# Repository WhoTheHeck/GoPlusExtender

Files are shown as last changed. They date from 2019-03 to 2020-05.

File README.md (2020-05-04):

# GoPlusExtender



Demo video (https://youtu.be/t_YZIJWOh5c)

## Idea
The goal of this project is to have the Go Plus modded in a way where it behaves comparable to the simple mod where you solder the vibration motor to the switch. In that simple mod basically everytime you plus would vibrate it will push the button automatically. At the end this results in constant button presses which on one hand drains the battery and on the other hand also always will push the button in events like "catch/spin succesfull", "item bag full", "connection-errors", etc.  
This project aims to react to Go Plus events in a smart way. Only pushing the button when it is necassary. While implementing that there were other convinient features addied like a rechargable LiPo-battery, low battery indicator, manual/automatic mode select, power save functionalities, change to manual catch mode for new pokemon and -very handy- custom vibration motor control! That enables custom vibration patterns which vibrate the motor in automation mode only when e.q. Go Plus disconnects from smartphone, item bag full or pokemon storage full.

## Concept
Hook into LED driving transistors to analize patterns.  
ATTiny45 reads LED signals, processes them, controlls button and vibration motor. Will be in deep sleep when using manual mode

## Partlist
- Battery - ZIPPY 240mAh 20C Single Cell (hobbyking)
- TP4056 Lithium Battery Charger and Protection Module
- PCB components (see BOM in files)
- additional 5.1k 0603 for charge controller PCB --> exchange R3, limits charge current to save limit around 250mA
- 1x 3D printed case top
- 1x 3D printed case bottom
- 1x 3D printed programmer adapter
- 2x PoGo-Pins small (A=4mm, goes in case, for powering GoPlusExtender from battery), (I got them from Aliexpress, Brand TangDa)
- 7x PoGo-Pins long (A=11.5mm, for programmer), (I got them from Aliexpress, Brand(?) TangDa)

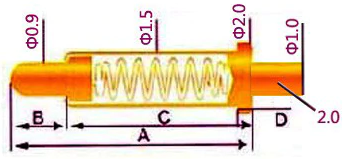
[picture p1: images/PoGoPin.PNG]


## Schematic
find v1 in files  

## Layout
Due to the tiny footprint the PCB had to be done as 4layer board.  
find v1 in files  

## PCB
Necessary components can be found in PCB_BoM.html  
Everything can still be soldered by hand. Using flux is recommended, especially the Analog Switch with the TSSOP-footprint will be trick otherwise.  

## Go Plus Solderpoints & Wiring
Soldering to the LED drivers is the most challenging part, take your time. In that case I recoommend securing the wires with some hot glue (not good practice... I know).  
o Polarity doesn't matter  
W1 --> GoPlusPower+ (from battery connector)  
W2 --> GoPlusPower- (from battery connector)  
W3 --> BatteryPower+ (from BatteryPCB)  
W4 --> BatteryPower- (from BatteryPCB)  
W5 --> switch (from GoPlus upper left)  
W6 --> GoPlus- (where motor was soldered to GoPlus) o  
W7 --> GoPlus+ (where motor was soldered to GoPlus) o  
W8 --> Motor- (desolder from GoPlus, solder here) o  
W9 --> Motor+ (desolder from GoPlus, solder here) o  
W10 --> LED blue (upper IC, upper middle leg)  
W16 --> LED green (lower IC, lower middle leg)  
W18 --> LED red (upper IC, lower middle leg)  
W11,W12,W13,W14,W17 --> Programmer (careful: here correct polarity is important!)  

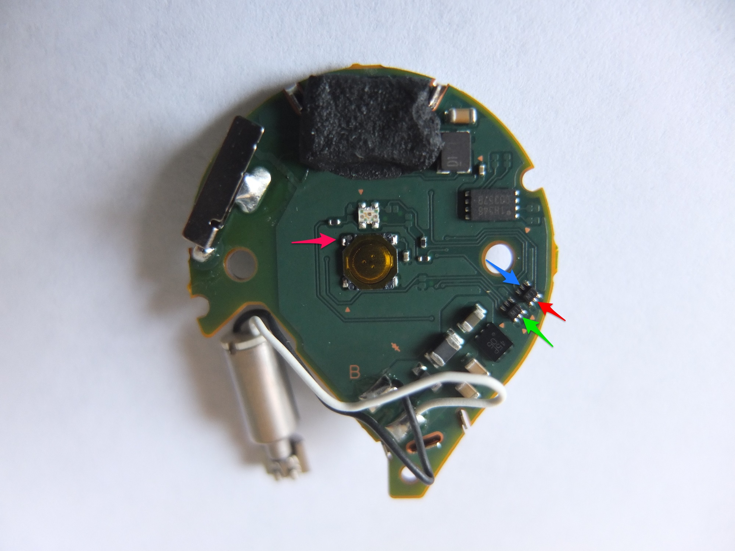
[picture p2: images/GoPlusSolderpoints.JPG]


## Programmer setup
3D printable programmer adapter in files. Needs PoGo-Pins with length = TBD!!!
W11 --> Uno GND
W --> Uno 13 - white
W --> Uno 12 - brown
W --> Uno 11 - purple
W --> Uno 10 - grey
W12 --> Uno 5V

Set mode to manuel when reprogramming!  
Search online for instructions to use Arduino Uno as programmer for ATTinys.

## Assembly

- 3D print case
- add PoGo-Pins to Case, position might needs to be adjusted a little by heating while soldering (needs case-rework)
- solder wires to ChargePCB
- wrap battery in isolation/kapton tape
(change ChargePCB current resistor to xxx ohms)
- attach battery to charge-PCB as seen in pictures
- put battery unit in bottom part, PCB will snapfit in place
- liftup battery, solder wires to PoGo-Pins
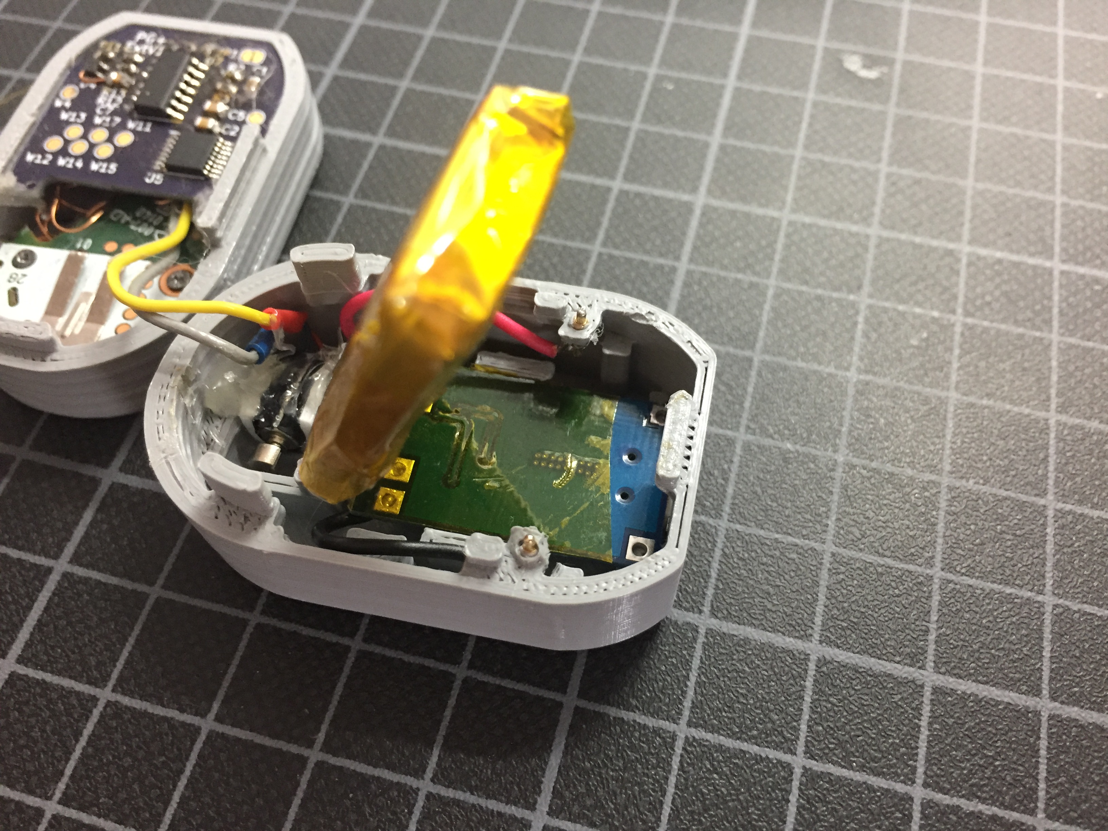
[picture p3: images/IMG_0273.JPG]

- desolder motor from GoPlus
- solder wires to GoPlus as shown above
- solder GoPlus-ExtenderPCB
- add motor
- solder wires to GoPlus as shown above
- put GoPlus push-button and silicon rubber in top case
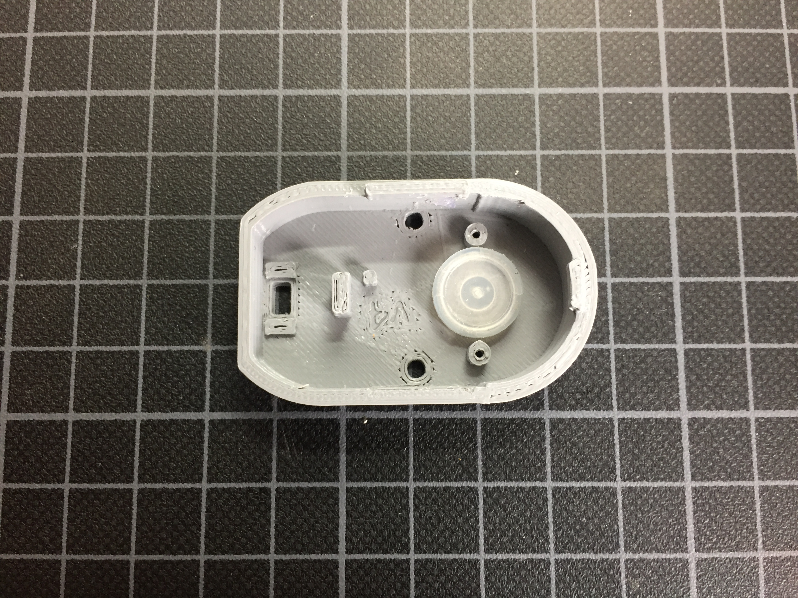
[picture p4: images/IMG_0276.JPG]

- put ExtenderPCB+GoPlus in top case, screw GoPlus in place
- put motor in bottom case, use foam to dampen vibrations, maybe add soft glue to hold in place

## Codebase

### Special variables
SIMULATING --> uncomment for checking code in Atmel Studio. Delays certain actions and skips EEPROM access.  
DEBUGING --> uncomment for upload to ATTiny with debug LED. Error LED will also light up when button gets pressed automatically.

### Main function
main():  
- defines input/output pins  
- defines interrupts  
	- input interrupt monitors LED patterns  
	- timer interrupt gets battery voltage every our (also whenever you power it up)  

### LED analizer functions
BlueHandle()  
GreenHandle()  
RedHandle()  
WhiteHandle()  
YellowHandle()  
- If the corresponding transistors get controlled the inputs at the ATTiny get pulled high, this enables interrupt-routine.  
WaitCount()  
- Counts how often function gets called, button gets pushed after ~30sec of idling to counteract a situation where GoPlus does not react to new Pokemon or Pokestops until useraction occures.  
TrackReset()  
- Reset the counted LED state after initalization or if no new LED-state has been detected for 30sec.  

### Randomized wait functions
This aims to make button presses more human like. There wont be any need to use this, but it's a nice savety feature.  
  
GetSeed()  
- Get & update seed value for randomized reactions.  
MyRandGet() 
- Generate new random-value. Initially based on seed.  
WaitRand()  
- Delay action by randomized time in ms.  

### Switch and motor control functions
SwitchFunc()  
- Controlles switch presses.
MotorFunc()  
- Controlles rumbling motor dependent on auto or manual mode.

### Power save / deep sleep functions
goToSleep()  
- Deep sleep ATTiny to save power.  
adc_init()  
- Enable ADC. Used to measure battery voltage.  
adc_disable()  
- Disable ADC after measurement to save power.  

### Battery monitoring functions
batt_meas()  
- Measure battery voltage.  
batt_state()  
- Read measured voltage. Enable low-battery-LED in 3.1 .. 3.2V range. LED will be disable at lower voltages to avoid additional battery drain.  

## Appendix

### Simulation
Attached in files is the simulation file that can be used with LTSpice. It shows how the PWM pulsed signal of the LED drivers gets smoothed and reduced by the diode and resistor divider to then be read by the ATTiny as a compatible digital input.  

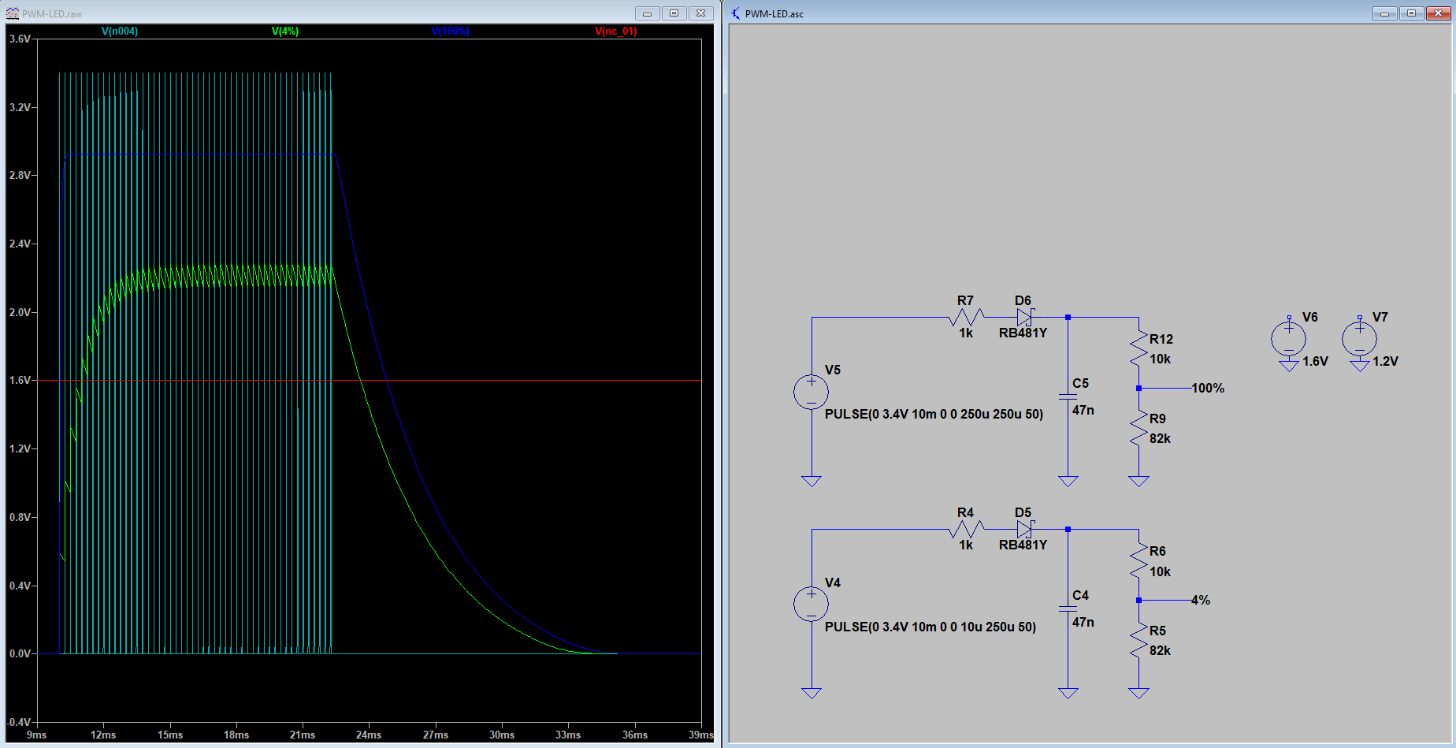
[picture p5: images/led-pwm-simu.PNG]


### GoPlus Model
Files contain derived GoPlus model usable as reference for modeling.  


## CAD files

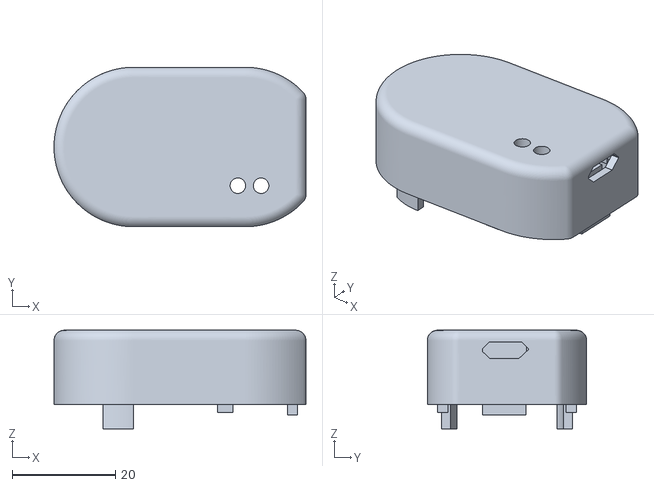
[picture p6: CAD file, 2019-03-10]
Modell/Case_bot_v5.stl
48.8 x 30.9 x 19.1

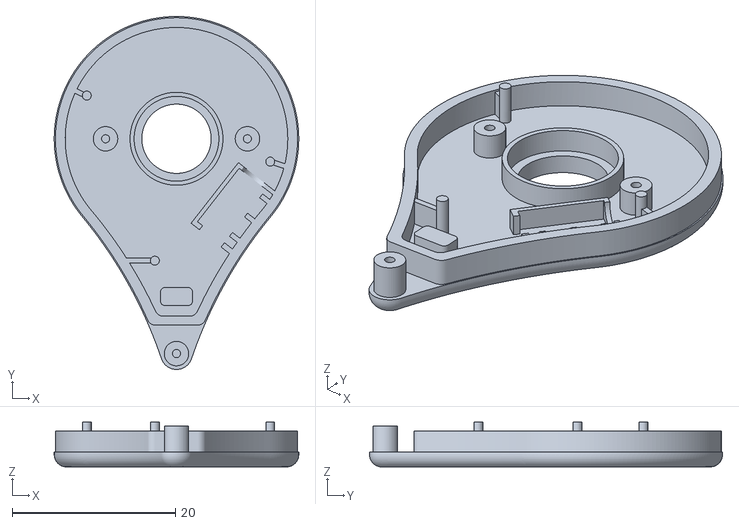
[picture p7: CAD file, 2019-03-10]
Modell/GoPlusModel_v1/top.stl
30.0 x 43.3 x 5.50

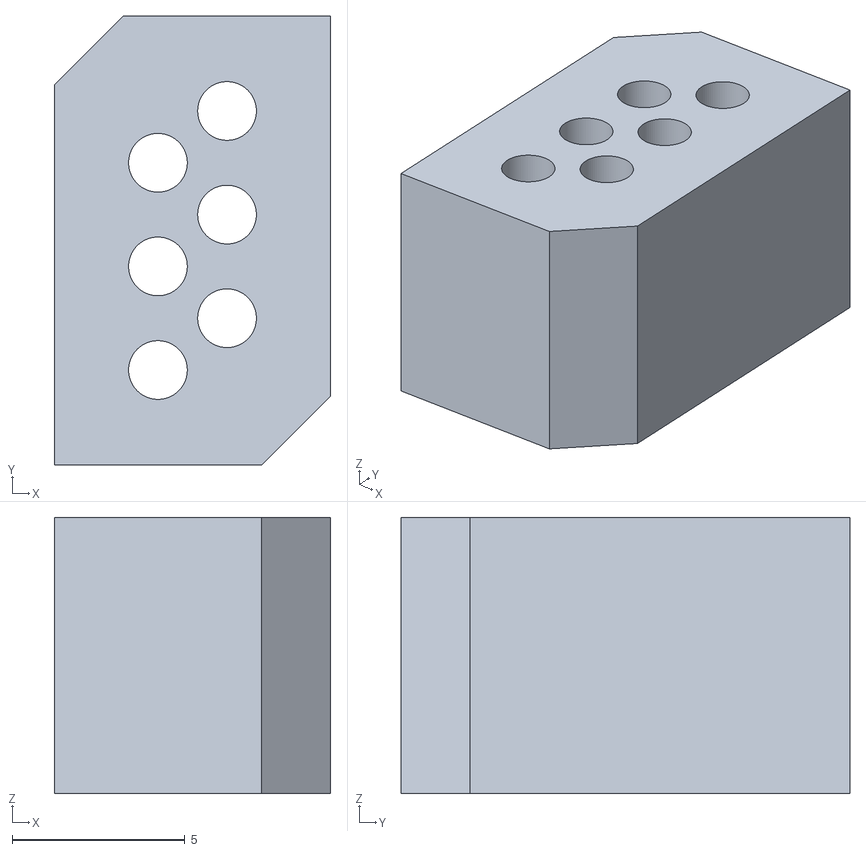
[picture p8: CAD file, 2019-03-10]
Modell/PoGo_Program_Connector/con_case.stl
8.00 x 13.0 x 8.00

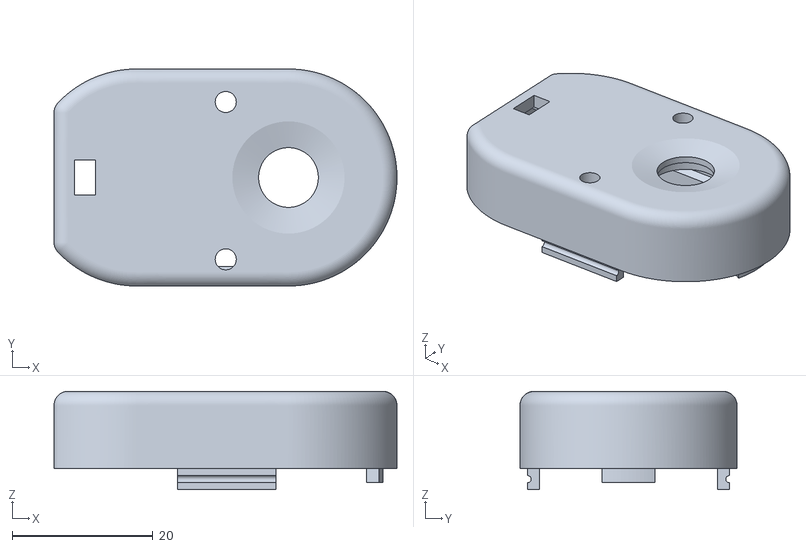
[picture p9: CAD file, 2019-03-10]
Modell/Case_top_v4.stl
48.8 x 30.9 x 14.0

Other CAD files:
Modell/GoPlusModel_v1/Button_plus.ipt
Modell/GoPlusModel_v1/GoPlus.iam
Modell/GoPlusModel_v1/bot.ipt
Modell/GoPlusModel_v1/clamp_ring.ipt
Modell/GoPlusModel_v1/motor.ipt
Modell/GoPlusModel_v1/pcb.ipt
Modell/GoPlusModel_v1/rubberpad.ipt
Modell/GoPlusModel_v1/screw.ipt
Modell/GoPlusModel_v1/top.ipt
Modell/PoGo_Program_Connector/PoGo_connector.iam
Modell/PoGo_Program_Connector/PoGo_pin.ipt
Modell/PoGo_Program_Connector/PoGo_pin_sml.ipt
Modell/PoGo_Program_Connector/con_case.ipt

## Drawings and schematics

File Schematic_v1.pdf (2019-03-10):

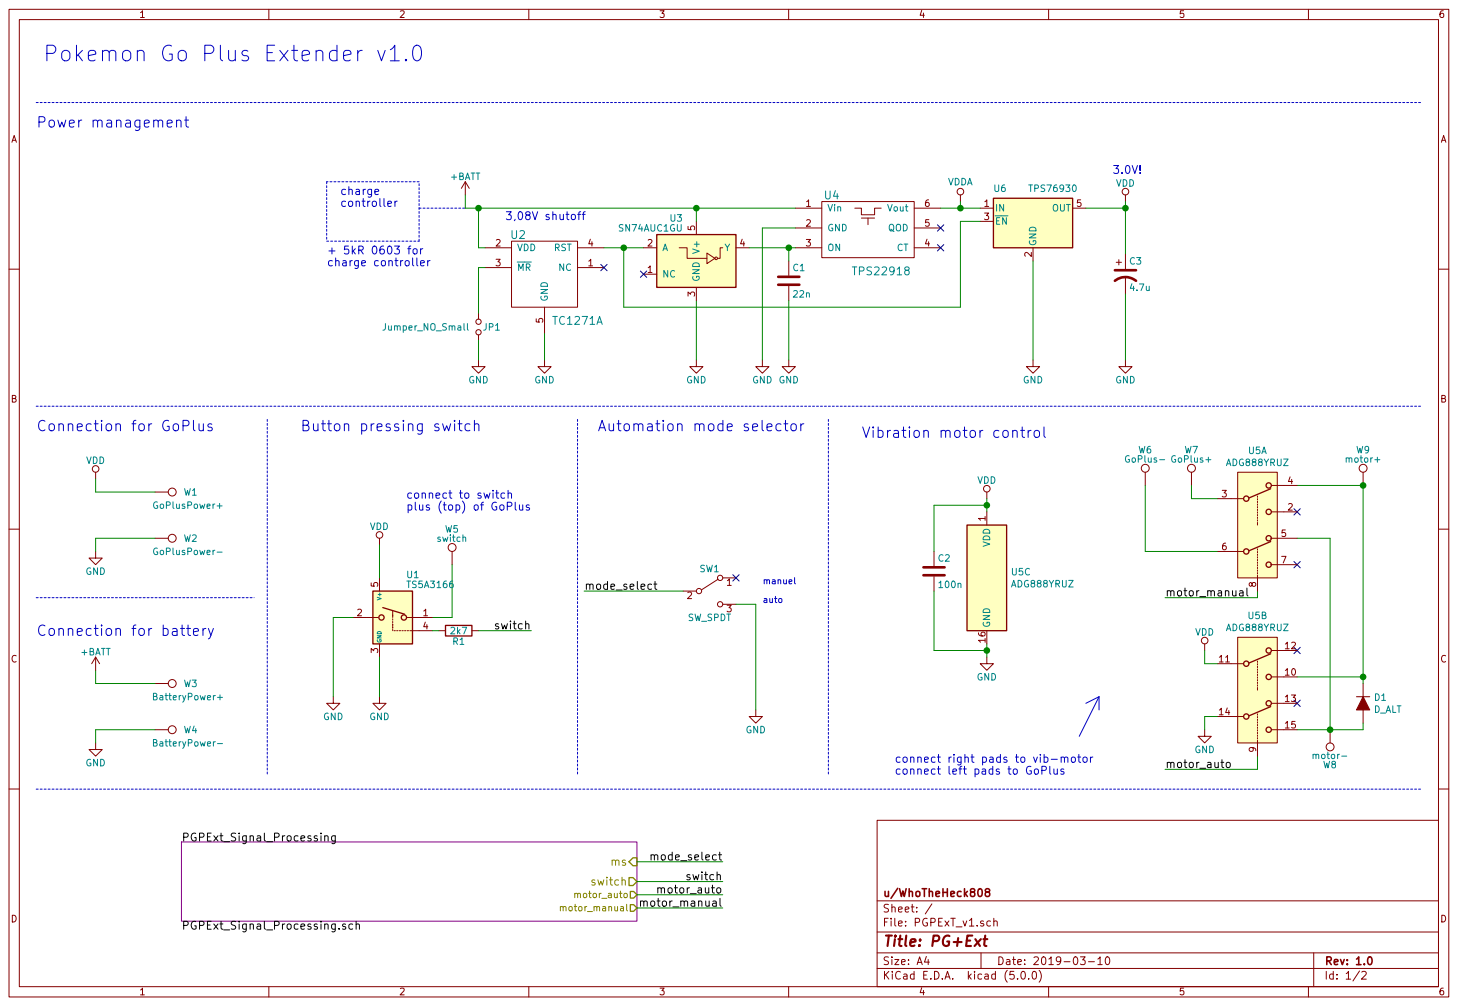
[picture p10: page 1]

switchms motor_auto motor_manual Pokemon Go Plus Extender v1.0

2 EN 3 OUT 5 U6 TPS76930 GND GND

switch GND W1 GoPlusPower+ W2 GoPlusPower- GND Connection for GoPlus

switch connect to switch plus (top) of GoPlus

connect left pads to GoPlus W5

+BATT Connection for battery

Id: 1/2 Title: PG+Ext

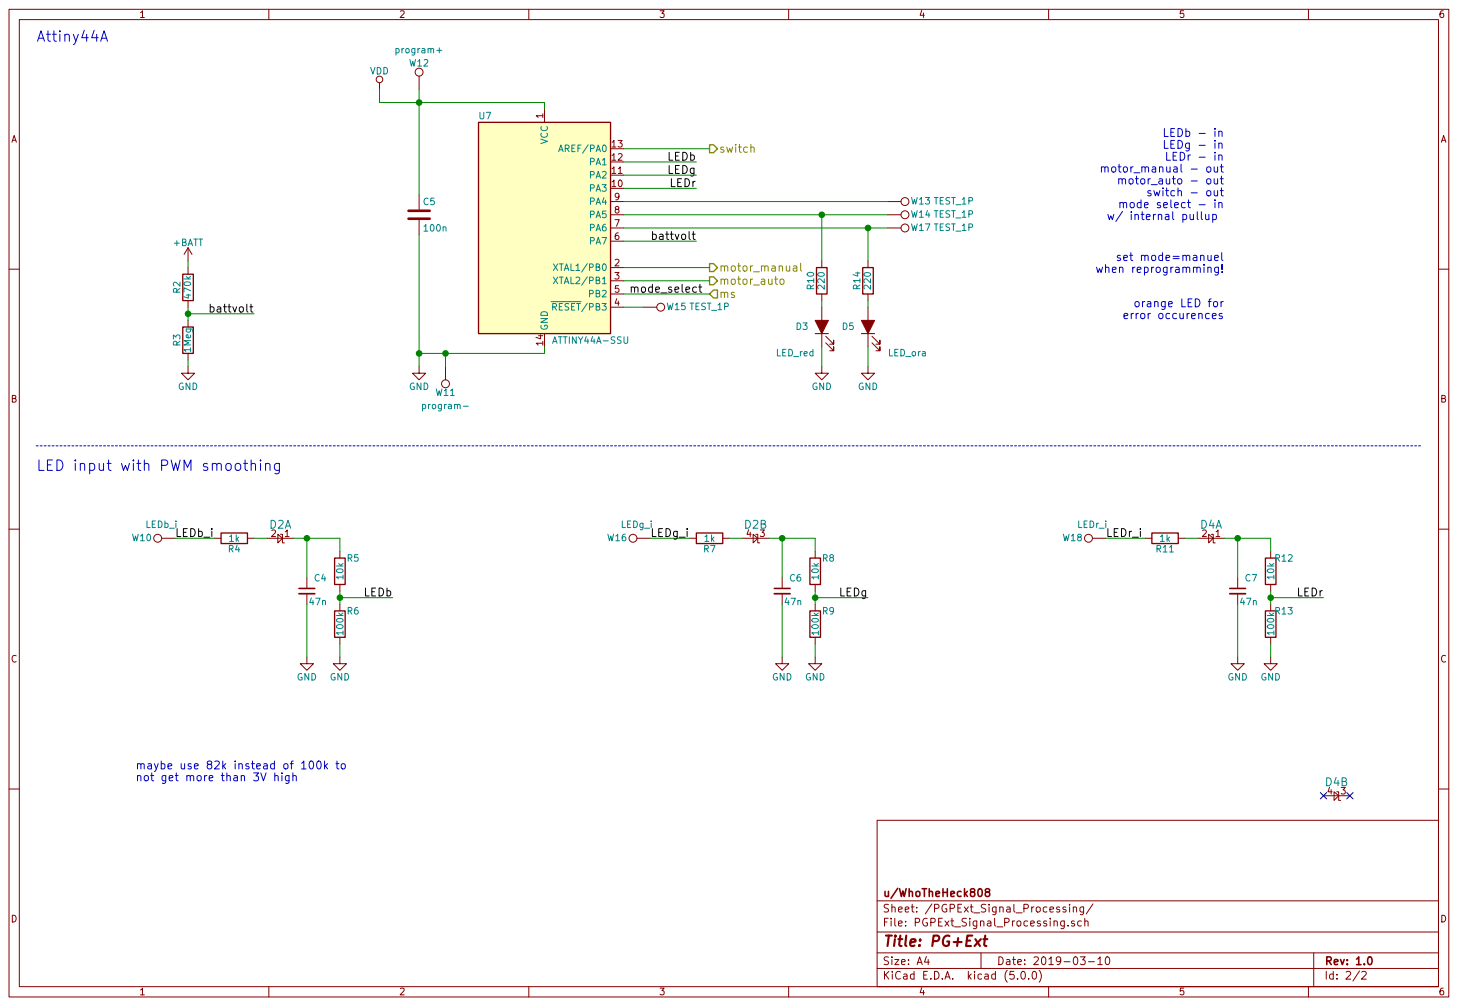
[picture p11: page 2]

1 PA3 10 PA2 11 PA1 12 AREF/PA0 13 GND 14 XTAL1/PB0 2 XTAL2/PB1 3 RESET/PB3 4 PB2 5 PA7 6 PA6 7 PA5 8 PA4 9 U7 ATTINY44A-SSU W12

motor_auto - out switch - out mode select - in w/ internal pullup C5

R13 100k GND maybe use 82k instead of 100k to

not get more than 3V high

File: PGPExt_Signal_Processing.sch
Id: 2/2 Title: PG+Ext

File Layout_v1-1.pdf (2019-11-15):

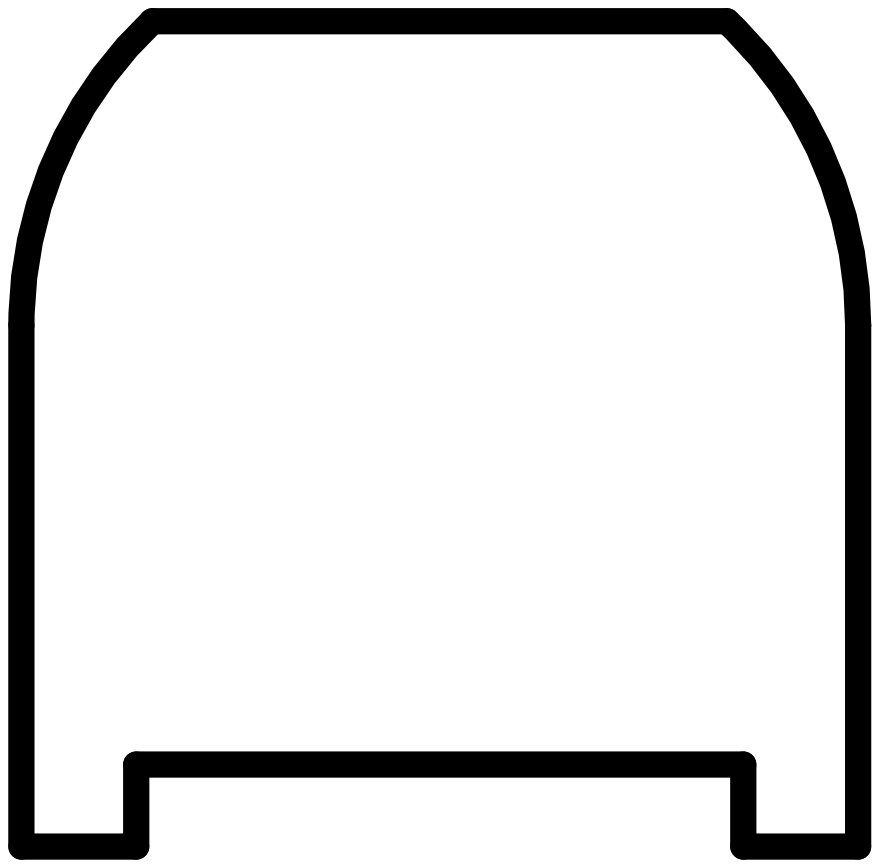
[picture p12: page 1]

Id: 1/1 Title: PoGo+Extender

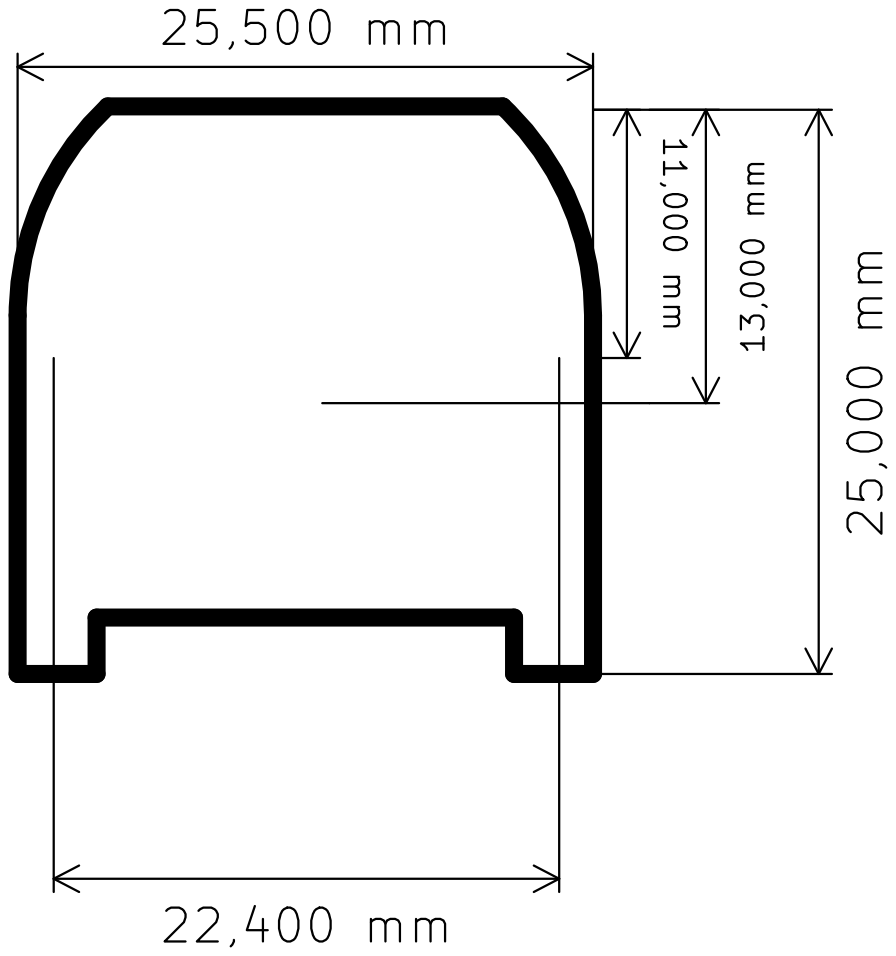
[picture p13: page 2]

Id: 1/1 Title: PoGo+Extender

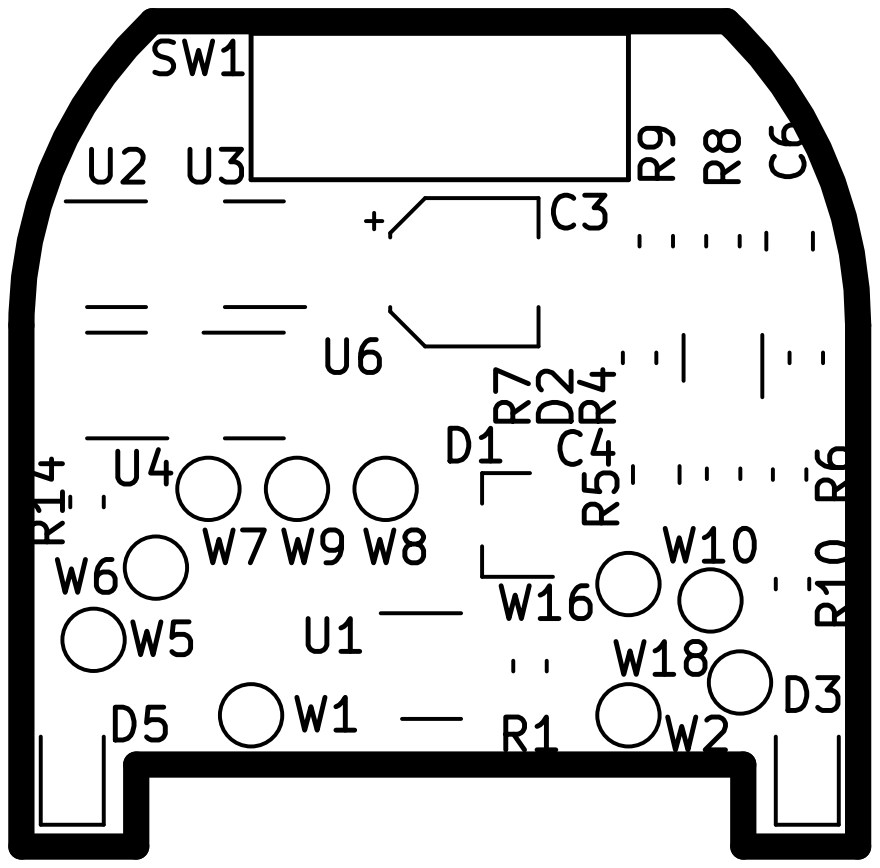
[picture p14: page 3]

Id: 1/1 Title: PoGo+Extender

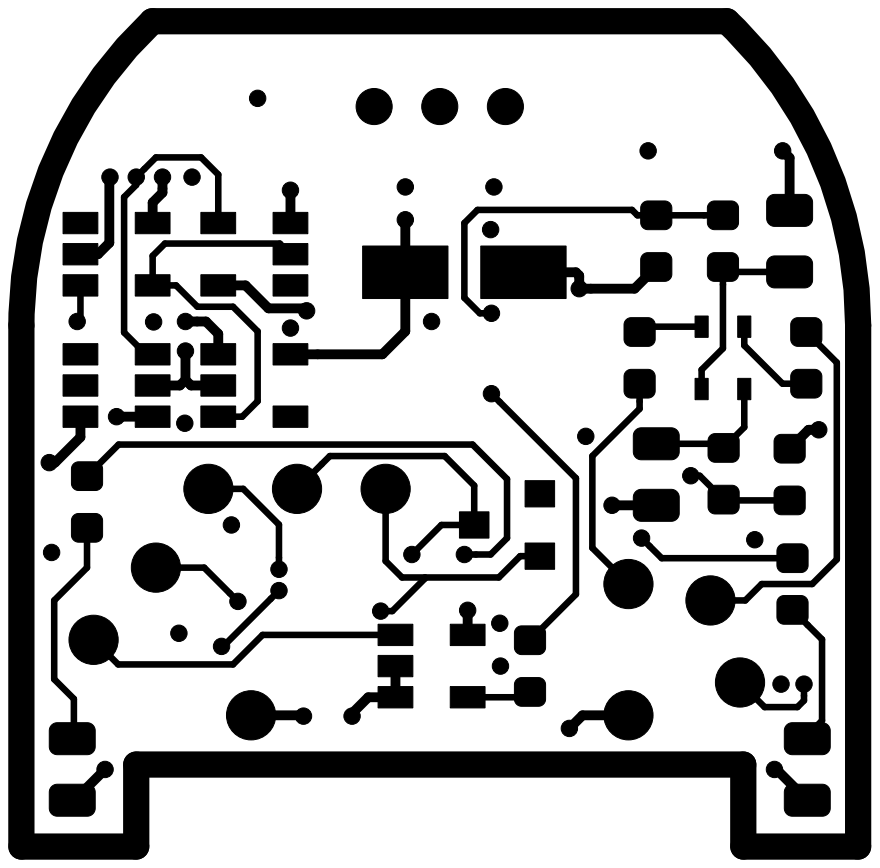
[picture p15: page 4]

Id: 1/1 Title: PoGo+Extender

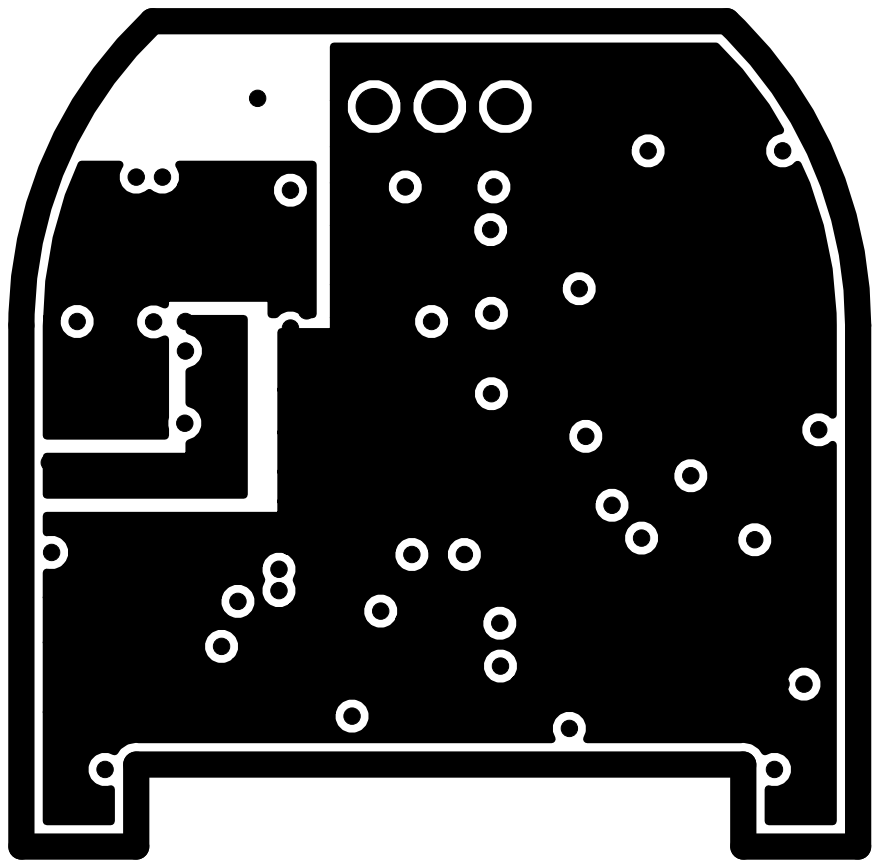
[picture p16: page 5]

Id: 1/1 Title: PoGo+Extender

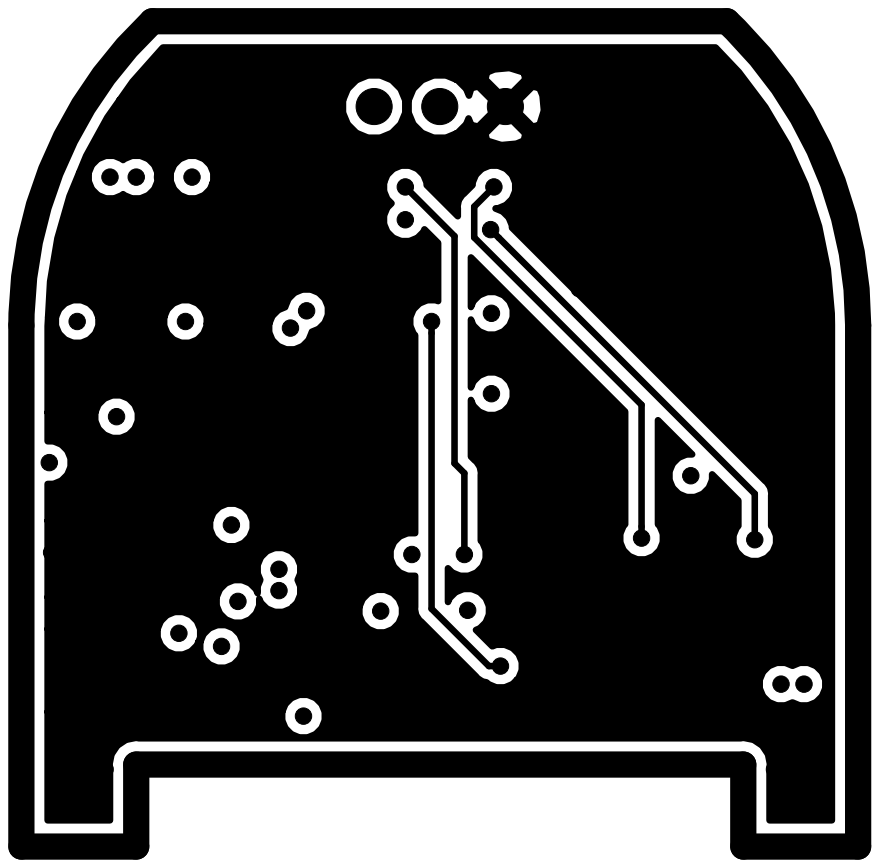
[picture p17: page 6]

Id: 1/1 Title: PoGo+Extender

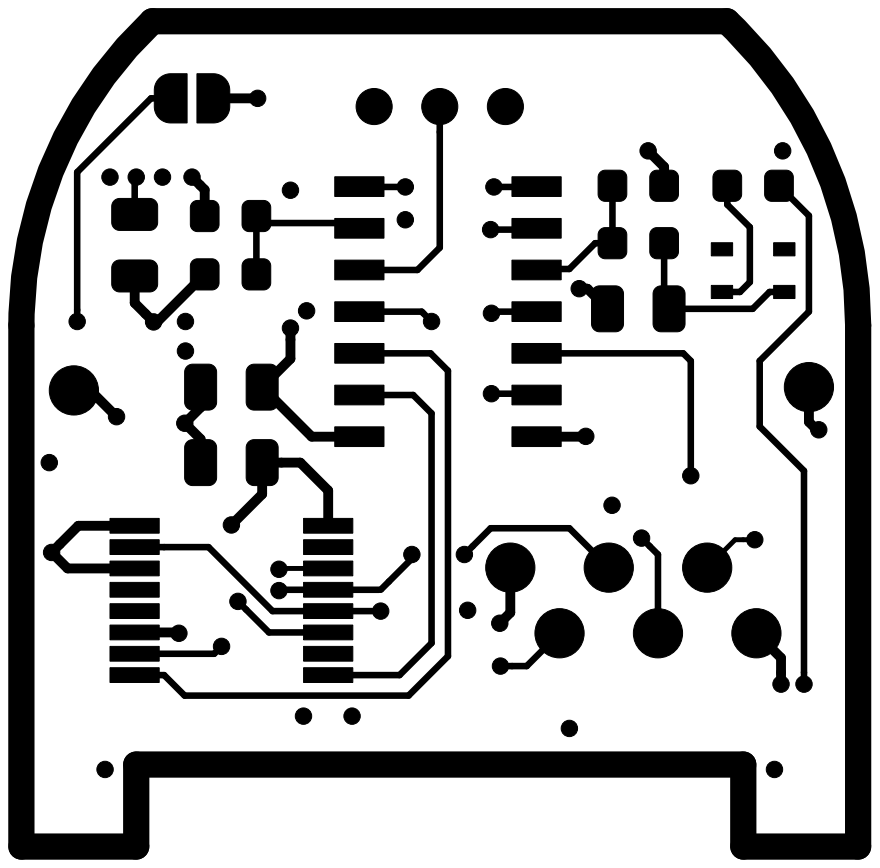
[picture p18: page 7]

Id: 1/1 Title: PoGo+Extender

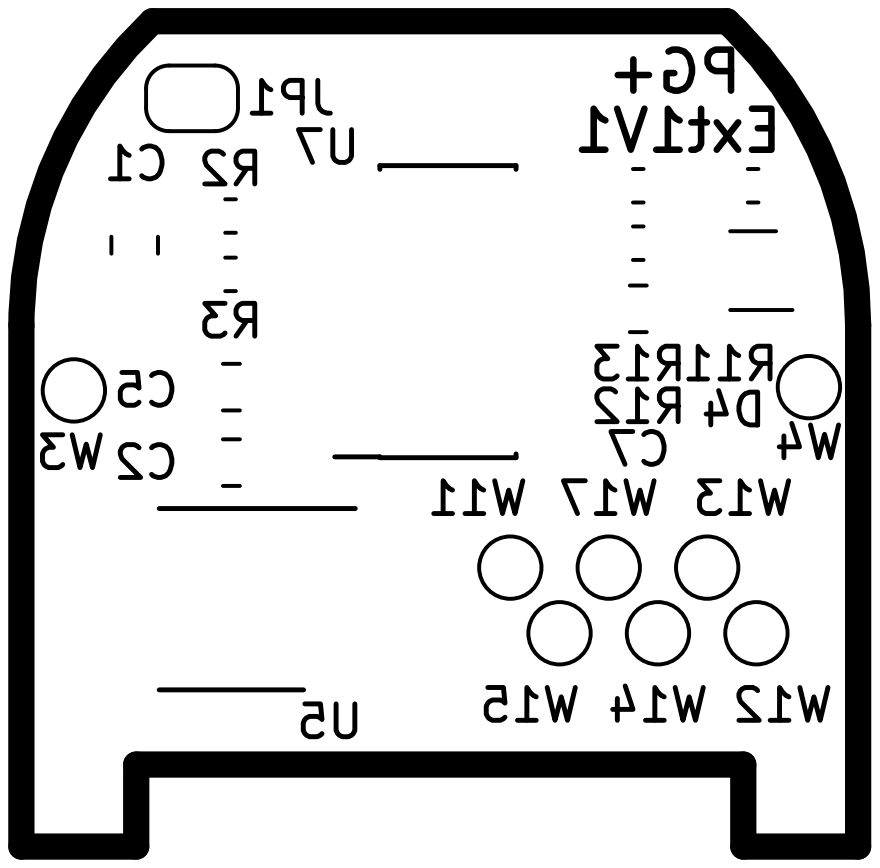
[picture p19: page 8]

Id: 1/1 Title: PoGo+Extender

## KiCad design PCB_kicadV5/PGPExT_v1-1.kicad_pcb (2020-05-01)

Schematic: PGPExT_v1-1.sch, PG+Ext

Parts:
C1: 22n; C_0805_2012Metric
C2: 100n; C_0805_2012Metric
C3: 4.7u; CP_Elec_4x5.3
D1: D_ALT; D_SOT-23_ANK
JP1: Jumper_NO_Small; SolderJumper-2_P1.3mm_Open_RoundedPad1.0x1.5mm
R1: 2k7; R_0603_1608Metric
SW1: SW_SPDT; SW_SSSS912500_ALPS
U1: TS5A3166; SOT-23-5
U2: TC1271A; SOT-23-5
U3: SN74AUC1GU; SOT-23-5
U4: TPS22918; SOT-23-6
U5: ADG888YRUZ; TSSOP-16_4.4x5mm_P0.65mm
U6: TPS76930; SOT-23-5
W1: GoPlusPower+; TestPoint_Pad_D1.5mm
W2: GoPlusPower-; TestPoint_Pad_D1.5mm
W3: BatteryPower+; TestPoint_Pad_D1.5mm
W4: BatteryPower-; TestPoint_Pad_D1.5mm
W5: switch; TestPoint_Pad_D1.5mm
W6: GoPlus-; TestPoint_Pad_D1.5mm
W7: GoPlus+; TestPoint_Pad_D1.5mm
W8: motor-; TestPoint_Pad_D1.5mm
W9: motor+; TestPoint_Pad_D1.5mm

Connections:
+BATT: U2.2, U3.5, U4.1, W3.1; also elsewhere on the board
/mode_select: SW1.2; also elsewhere on the board
/motor_auto: U5.9; also elsewhere on the board
/motor_manual: U5.8; also elsewhere on the board
/switch: R1.2; also elsewhere on the board
GND: C1.2, C2.2, C3.2, JP1.2, SW1.3, U1.2, U1.3, U2.5, U3.3, U4.2, U5.14, U5.16, U6.2 (GND), W2.1, W4.1; also elsewhere on the board
unnamed: C1.1, U3.4, U4.3
unnamed: D1.1, U5.4, U5.10, W9.1
unnamed: D1.2, U5.5, U5.15, W8.1
unnamed: JP1.1, U2.3
unnamed: R1.1, U1.4
unnamed: U1.1, W5.1
unnamed: U2.4, U3.2, U6.3 (~EN~)
unnamed: U5.3, W7.1
unnamed: U5.6, W6.1
VDD: C2.1, C3.1, U1.5, U5.1, U5.11, U6.5 (OUT), W1.1; also elsewhere on the board
VDDA: U4.6, U6.1 (IN)

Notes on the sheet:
+ 5kR 0603 for charge controller
charge controller
connect right pads to vib-motor connect left pads to GoPlus
connect to switch plus (top) of GoPlus
Connection for GoPlus
Automation mode selector
Vibration motor control
Button pressing switch
Power management
3.0V!
Pokemon Go Plus Extender v1.0
3,08V shutoff
manuel auto
Connection for battery

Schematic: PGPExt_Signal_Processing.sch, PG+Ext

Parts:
C4, C6, C7: 47n; C_0805_2012Metric
C5: 100n; C_0805_2012Metric
D2, D4: D_Schottky_Dual; SOT-343_SC-70-4
D3: LED_red; LED_0805_2012Metric
D5: LED_ora; LED_0805_2012Metric
R2: 470k; R_0603_1608Metric
R3: 1Meg; R_0603_1608Metric
R4, R7, R11: 1k; R_0603_1608Metric
R5, R8, R12: 10k; R_0603_1608Metric
R6, R9, R13: 100k; R_0603_1608Metric
R10, R14: 220; R_0603_1608Metric
U7: ATTINY44A-SSU; SOIC-14_3.9x8.7mm_P1.27mm
W10: LEDb_i; TestPoint_Pad_D1.5mm
W11: program-; TestPoint_Pad_D1.5mm
W12: program+; TestPoint_Pad_D1.5mm
W13, W14, W15, W17: TEST_1P; TestPoint_Pad_D1.5mm
W16: LEDg_i; TestPoint_Pad_D1.5mm
W18: LEDr_i; TestPoint_Pad_D1.5mm

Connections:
+BATT: R2.2; also elsewhere on the board
/PGPExt_Signal_Processing/LEDb: R5.2, R6.1, U7.12 (PA1)
/PGPExt_Signal_Processing/LEDb_i: R4.2, W10.1
/PGPExt_Signal_Processing/LEDg: R8.2, R9.1, U7.11 (PA2)
/PGPExt_Signal_Processing/LEDg_i: R7.2, W16.1
/PGPExt_Signal_Processing/LEDr: R12.2, R13.1, U7.10 (PA3)
/PGPExt_Signal_Processing/LEDr_i: R11.2, W18.1
/PGPExt_Signal_Processing/battvolt: R2.1, R3.2, U7.6 (PA7)
/mode_select: U7.5 (PB2); also elsewhere on the board
/motor_auto: U7.3 (XTAL2/PB1); also elsewhere on the board
/motor_manual: U7.2 (XTAL1/PB0); also elsewhere on the board
/switch: U7.13 (AREF/PA0); also elsewhere on the board
GND: C4.2, C5.2, C6.2, C7.2, D3.1, D5.1, R3.1, R6.2, R9.2, R13.2, U7.14 (GND), W11.1; also elsewhere on the board
unnamed: C4.1, D2.1, R5.1
unnamed: C6.1, D2.4, R8.1
unnamed: C7.1, D4.1, R12.1
unnamed: D2.2, R4.1
unnamed: D2.3, R7.1
unnamed: D3.2, R10.1
unnamed: D4.2, R11.1
unnamed: D5.2, R14.1
unnamed: R10.2, U7.8 (PA5), W14.1
unnamed: R14.2, U7.7 (PA6), W17.1
unnamed: U7.4 (~RESET~/PB3), W15.1
unnamed: U7.9 (PA4), W13.1
VDD: C5.1, U7.1 (VCC), W12.1; also elsewhere on the board

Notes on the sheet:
LEDb - in LEDg - in LEDr - in motor_manual - out motor_auto - out switch - out mode select - in w/ internal pullup
orange LED for error occurences
maybe use 82k instead of 100k to not get more than 3V high
Attiny44A
LED input with PWM smoothing
set mode=manuel when reprogramming!

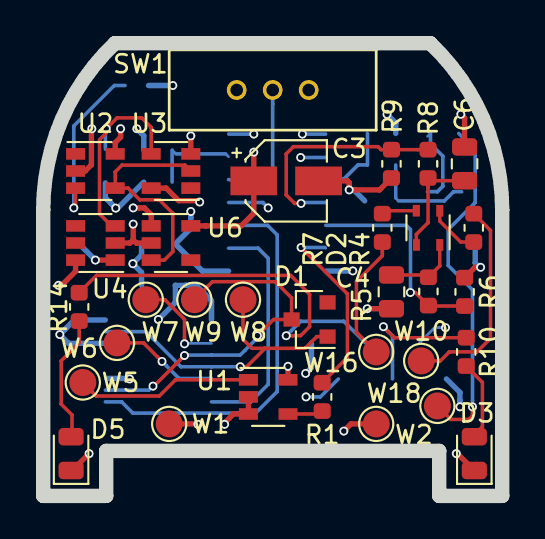
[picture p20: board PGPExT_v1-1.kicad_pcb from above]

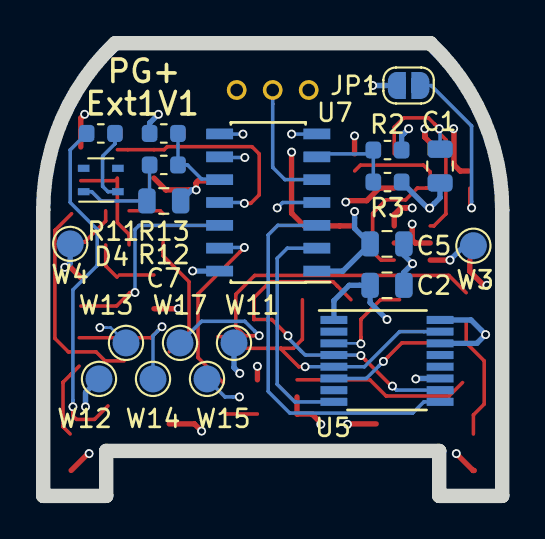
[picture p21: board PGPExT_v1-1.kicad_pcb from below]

Board: 4 copper layers, 25.5 x 25.2 mm, 53 parts (21 on the bottom side), 36 nets.

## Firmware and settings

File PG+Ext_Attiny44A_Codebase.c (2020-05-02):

/*
 * PGPExt_44A.c
 *
 * Created: 13.08.2018 18:42:17
 * Author : WhoTheHeck
 */ 

/*
11 IOs verfügbar
!! PINB2 == INT0 !!

PINA:
PINA0 - led_blue_i
PINA1 - led_green_i
PINA2 - led_red_i
PINA3 - motor_manual_o low enable
PINA4 - motor_auto_o   high enable
PINA0 - button_o
PINA6 - error_led_o

mode_select (input):
PINB2 == 0 -> autocatch
PINB2 == 1 -> manual catch

PINB0,PINA1,PINA2 - reserved/reprogramming

*/

#include <avr/io.h>                                         // AVR command set
#include <stdint.h>                                         // variable command set
#include <avr/eeprom.h>                                     // EEPROM-access
#include <stdlib.h>
#include <util/delay.h>                                     // _delay_ms()
#include <avr/interrupt.h>                                  // Interrupt command set
#include <avr/power.h>                                      // power mangement, prescaler
#include <avr/sleep.h>                                      // power down

#define MYRAND_MULTIPLIER  17
#define MYRAND_CONSTANT    37
#define EEPROM_DEF 0xFF
//#define SIMULATING
//#define DEBUGING

uint8_t mcucr1, mcucr2;

uint8_t g_nLastRandom;
uint8_t EEMEM eeSeed;
uint8_t startup = 1;
uint8_t LED_state = 0b00000000;
uint8_t LED_state_n = 0b00000000;
uint8_t LED_state_zero = 0b00000001;
uint16_t idle_cnt=0;
uint16_t colortracker[3][8];                                        //8 colums for 8 values with 3 colors each
uint8_t colorrow;
uint8_t colorcol;
uint8_t pattern=0b000;
uint8_t battime = 0;
float BatVal;
float EEMEM eeBatVal;


ISR(PCINT0_vect);
ISR(TIM1_COMPA_vect);
ISR(EXT_INT0_vect);

void BlueHandle();
void GreenHandle();
void RedHandle();
void WhiteHandle();
void YellowHandle();

uint8_t MyRandGet();
void GetSeed();
void WaitRand();

void SwitchFunc();
void MotorFunc();

void goToSleep();
void WaitCount();
void TrackReset();

void adc_init();
void adc_disable();
void batt_meas();
void batt_state();


void GetSeed()
{
    uint8_t nSeed;
    
    #ifndef SIMULATING
    nSeed = eeprom_read_byte (&eeSeed);     
    #else
    nSeed = 0;
    #endif
    
    if (nSeed == 255)                                       //incement value by 1 till 255
        nSeed = 1;
    else
        nSeed++;
    
    #ifndef SIMULATING
    eeprom_busy_wait(); 
    eeprom_write_byte(&eeSeed,nSeed);                       //write new eeprom value
    #endif

    g_nLastRandom = nSeed;
}

uint8_t MyRandGet() /* credits: mikrocontroller.net/topic/112114 */
{
    //copy into local variables to avoid 16-bit integer expansion
    uint8_t Multiplier = MYRAND_MULTIPLIER;
    uint8_t Constant = MYRAND_CONSTANT;

    //implicit %256 by 8-bit datatype overflow
    g_nLastRandom = (g_nLastRandom * Multiplier + Constant)/* % MYRAND_MODULO*/;
    
    if (startup==1)                                         // save first rand-value after startup
        {
            #ifndef SIMULATING
            eeprom_update_byte(&eeSeed, g_nLastRandom);     //save new seed EEPROM value
            #endif
            startup=0;
        }
    
    return g_nLastRandom /* % MYRAND_MODULO*/;
}

void WaitRand()
{
    int i = 0;
    for (i=0;i<(g_nLastRandom+150); i++)                    // values between 0..256, add 150 for realistic wait time
    {
        #ifndef SIMULATING
        _delay_ms(1);
        #endif
    }
    MyRandGet();                                            //get new g_nLastRandom
}

void SwitchFunc()
{
    WaitRand();                                             // wait random time
    PORTA |= (1<<PINA0);                                    // set button_out=high
    #ifdef DEBUGING
    PORTA |= (1<<PINA6);                                    // led for debug
    #endif
    WaitRand();
    PORTA &= ~(1<<PINA0);                                   // set button_out=low
    #ifdef DEBUGING
    PORTA &= ~(1<<PINA6);
    #endif
}

void goToSleep()                                            // credits: forum.arduino.cc/index.php?topic=83826.0
{
    set_sleep_mode(SLEEP_MODE_PWR_DOWN);
    cli();                                                  //disable interrupt first; against switch bounce
    PORTA &= ~(1<<PINA5);                                   //make sure low power led is off
    PORTB &= ~(1<<PINB0);                                   //PINB0 low - standard motor mode
    power_all_disable ();                                   //turn off all modules
    battime = 0;                                            //reset battery/adc timer counter
    GIMSK = (1<<INT0);                                      //enable INT0
    MCUCR &= ~(1<<(ISC01) | 1<<(ISC00));                    //INT0 on low level

    sleep_enable();
    sleep_bod_disable();                                    //turn off the brown-out detector.
    sei();                                                  //ensure interrupts enabled so we can wake up again
    sleep_cpu();                                            //go to sleep
    sleep_disable();
    cli();                                                  //wake up here, disable interrupts
    GIMSK = (1<<PCIE0);                                     //set PCIE Bit to enable PCINT interrupt
    PCMSK0 = 0b00001110;                                    //define LED-pins as interrupts
    batt_meas();                                            //measure batvoltage
    PORTB |= (1<<PINB0);                                    //PINB0 high - motor disconnected from Go+
    sei();                                                  //enable interrupts again (but INT0 is disabled from above)
    power_timer1_enable();                                  //enable battery/adc counter
    SwitchFunc();
}

ISR(EXT_INT0_vect) {}                                       //nothing to actually do here, the interrupt just wakes us up!

void WaitCount()
{
    // global var counts how often function gets called, button gets pushed after ~30sec of idling to counteract a situation
	// where GoPlus does not react to new Pokemon or Pokestops until useraction occures
    if (!( PINB & (1<<PINB2) )) idle_cnt=idle_cnt+1;        // count only if autocatching
    #ifndef SIMULATING
    _delay_ms(30);
    #endif                                   
    if (idle_cnt > 1000 && (!( PINB & (1<<PINB2) )) )       // delay 30ms 100 times == 30sec; if autocatching
        {
            WaitRand();                                     // randomize
            SwitchFunc();
            TrackReset();
            idle_cnt=0;
        }
    if ( PINB & (1<<PINB2) )                                // sleepmode if PBIN2 == 1
        {
            TrackReset();
            goToSleep();
        }
}

void TrackReset()
{
    for(colorrow = 0; colorrow < 3; colorrow++)
    {
        for(colorcol = 0; colorcol < 8; colorcol++)
        colortracker[colorrow][colorcol]=0;
    }
    colorcol=0;
    colorrow=0;
    PORTA &= ~(1<<PINA6);                                   //unset error_LED -> flashing state
}

void BlueHandle()
{
    // first bl -> just register || counteract handling of successfull catch event
    if ((colorcol==0 && (colortracker[0][0] == 0 && colortracker[1][0] == 0 && colortracker[2][0] == 0))
    || (colorcol==1 && (colortracker[0][0] == 0 && colortracker[1][0] == 0 && colortracker[2][0] == 1)))
    {
        TrackReset();
        colorrow=0;                                     	//set state==blue
        colortracker[colorrow][colorcol]=1;             	//set state==blue
        colorcol=colorcol+1;                            	//incement column
        PORTA &= ~(1<<PINA6);                           	//set error_led=low
    }
    // bl, bl -> switch
    else if (colorcol==1 && (colortracker[0][colorcol-1] == 1 && colortracker[1][colorcol-1] == 0 && colortracker[2][colorcol-1] == 0))
    {
        colorrow=0;
        colortracker[colorrow][colorcol]=1;
        colorcol=colorcol+1;
        SwitchFunc();
    }
    //bl, bl, bl -> maybe just second blink after buttonpush
    else if ((colorcol==2 || colorcol==3) && (colortracker[0][colorcol-1] == 1 && colortracker[1][colorcol-1] == 0 && colortracker[2][colorcol-1] == 0))
    {
        colorrow=0;
        colortracker[colorrow][colorcol]=1;
        colorcol=colorcol+1;
    }
    // bl, bl, bl, bl -> seach for device == disconnected, error!
    else if (colorcol==4 && (colortracker[0][colorcol-1] == 1 && colortracker[1][colorcol-1] == 0 && colortracker[2][colorcol-1] == 0))
    {
        PORTA |= (1<<PINA6);                            	//set error_led=high
        //switchfunc has already been activated after bl-bl state, so wait, reset, check again:
        #ifndef SIMULATING
        _delay_ms(1000);                                	// 1 sec bc wait for human action
        #endif
        TrackReset();                                   	// reset colortracker, start over, see if still disconected
        pattern=0b111;//1;
        MotorFunc();
    }
    // other
    else
    {
        TrackReset();
        PORTA |= (1<<PINA6);
        pattern=0b001;//6;
        MotorFunc();
    }
    LED_state=0;
    sei();
}

void GreenHandle()
{
    // first gr -> switch   || counteract handling of successfull catch event
    if ((colorcol==0 && (colortracker[0][0] == 0 && colortracker[1][0] == 0 && colortracker[2][0] == 0))
    || (colorcol==1 && (colortracker[0][0] == 0 && colortracker[1][0] == 0 && colortracker[2][0] == 1)))
    {
        colorrow=1;                                     	//set state==green
        colortracker[colorrow][colorcol]=1;             	//set state==green
        colorcol=colorcol+1;                            	//incement column
        PORTA &= ~(1<<PINA6);                           	//set error_led=low
        SwitchFunc();
    }
    // gr, gr -> maybe just second blink after buttonpush
    else if (colorcol>0 && (colortracker[0][colorcol-1] == 0 && colortracker[1][colorcol-1] == 1 && colortracker[2][colorcol-1] == 0))
    {
        colorrow=1;
        colortracker[colorrow][colorcol]=1;
        colorcol=colorcol+1;
    }
    //bl, gr -> spin successful -> delete matrix
    else if (colorcol>0 && (colortracker[0][colorcol-1] == 1 && colortracker[1][colorcol-1] == 0 && colortracker[2][colorcol-1] == 0))
    {
        PORTA &= ~(1<<PINA6);
        TrackReset();
    }
    //other
    else
    {
        TrackReset();
        PORTA |= (1<<PINA6);
        pattern=0b001;//6;
        MotorFunc();
    }
    LED_state=0;
    sei();
}

void RedHandle()
{
    // r -> disconnect or no signal
    if (colorcol==0 && (colortracker[0][0] == 0 && colortracker[1][0] == 0 && colortracker[2][0] == 0))
    {
        PORTA |= (1<<PINA6);                            	//set error_led=high
        TrackReset();
        pattern=0b000;//2;
        MotorFunc();
    }
    // gr, w, w, w, r or gr, w, w, r or gr, w, r -> end of catch-event
    else if (colorcol>0 && (colortracker[0][colorcol-1] == 1 && colortracker[1][colorcol-1] == 1 && colortracker[2][colorcol-1] == 1))
    {
        TrackReset();
        colorrow=2;
        colortracker[colorrow][colorcol]=1;
        colorcol=colorcol+1;
    }
    //r, r -> 2nd red after catch-fail
    else if (colorcol==1 && (colortracker[0][colorcol-1] == 0 && colortracker[1][colorcol-1] == 0 && colortracker[2][colorcol-1] == 1))
    {
        colorrow=2;
        colortracker[colorrow][colorcol]=1;
        colorcol=colorcol+1;
    }
    //r, r, r -> 3rd red after catch-fail - reset
    else if (colorcol==2 && (colortracker[0][colorcol-1] == 0 && colortracker[1][colorcol-1] == 0 && colortracker[2][colorcol-1] == 1))
    {
        TrackReset();
        PORTA &= ~(1<<PINA6);
    }
    // gr, r -> storage full
    else if (colorcol>0 && (colortracker[0][colorcol-1] == 0 && colortracker[1][colorcol-1] == 1 && colortracker[2][colorcol-1] == 0))
    {
        PORTA |= (1<<PINA6);
        TrackReset();
        pattern=0b100;//3;
        MotorFunc();
    }
    // b, r -> stop out of reach
    else if (colorcol>0 && (colortracker[0][colorcol-1] == 1 && colortracker[1][colorcol-1] == 0 && colortracker[2][colorcol-1] == 0))
    {
        TrackReset();
        PORTA &= ~(1<<PINA6);
    }
    //other
    else
    {
        TrackReset();
        PORTA |= (1<<PINA6);
        pattern=0b001;//6;
        MotorFunc();
    }
    LED_state=0;
    sei();
}

void WhiteHandle()
{
    // gr, w -> save state
    if (colorcol>0 && (colortracker[0][colorcol-1] == 0 && colortracker[1][colorcol-1] == 1 && colortracker[2][colorcol-1] == 0))
    {
        for(colorrow = 0; colorrow < 3; colorrow++)     	//set state==white
        {
            colortracker[colorrow][colorcol]=1;
        }
        colorcol=colorcol+1;                            	//incement column
        PORTA &= ~(1<<PINA6);                           	//set error_led=low
    }
    // w, w -> save state
    else if (colorcol>0 && (colortracker[0][colorcol-1] == 1 && colortracker[1][colorcol-1] == 1 && colortracker[2][colorcol-1] == 1))
    {
        for(colorrow = 0; colorrow < 3; colorrow++)
        {
            colortracker[colorrow][colorcol]=1;
        }
        colorcol=colorcol+1;
        PORTA &= ~(1<<PINA6);
    }
    // b, w -> bag full -> orange LED
    else if (colorcol>0 && (colortracker[0][colorcol-1] == 1 && colortracker[1][colorcol-1] == 0 && colortracker[2][colorcol-1] == 0))
    {
        PORTA |= (1<<PINA6);                            	//set error_led=high
        TrackReset();
        pattern=0b110;//4;
        MotorFunc();
    }
    // other
    else
    {
        TrackReset();
        PORTA |= (1<<PINA6);
        pattern=0b001;//6;
        MotorFunc();
    }
    LED_state=0;
    sei();
}

void YellowHandle()
{
    // first yellow -> new mon!   || counteract handling of successfull catch event
    if ((colorcol==0 && (colortracker[0][0] == 0 && colortracker[1][0] == 0 && colortracker[2][0] == 0))
    ||  (colorcol==1 && (colortracker[0][0] == 0 && colortracker[1][0] == 0 && colortracker[2][0] == 1)))

    {
        TrackReset();
        //maybe signal to user or use switch to decide if catch auto or manual. for now only indicate to manual catch
        PORTA |= (1<<PINA6);                            	//set error_led=high
        pattern=0b101;//5;
        MotorFunc();
    }
    // other
    else
    {
        TrackReset();
        PORTA |= (1<<PINA6);
        pattern=0b001;//6;
        MotorFunc();
    }
    LED_state=0;
    sei();
}

void MotorFunc()
{
    uint16_t d_short = 200;
    uint16_t d_long = 400;
    uint16_t d_sleep = 100;
    uint8_t i=0;
    
    for (i=0;i<3;i++)
        {
            PORTB |= (1<<PINB1);
            if (pattern & (1<<i) )  
            {
                #ifndef SIMULATING
                _delay_ms(d_long);
                #endif
            }
            else
                #ifndef SIMULATING
                _delay_ms(d_short);
                #endif
            PORTB &= ~(1<<PINB1);
            #ifndef SIMULATING
            _delay_ms(d_sleep);
            #endif
        }
    //pattern=0;
}

ISR(PCINT0_vect)
{
    if (PINA & (1<<PINA1) )                                 //ledb
        LED_state_n |= (1<<0);
    else LED_state_n &= ~(1<<0);
    if (PINA & (1<<PINA2) )                                 //ledg
        LED_state_n |= (1<<1);
    else LED_state_n &= ~(1<<1);
    if (PINA & (1<<PINA3) )                                 //ledr
        LED_state_n |= (1<<2);
    else LED_state_n &= ~(1<<2);

    if (LED_state_n != 0                                    //Variable nur speichern, wenn nicht Wechsel auf 0 erfolgte
        && LED_state_zero == 1                              //nur speichern wenn vorher zustand 0 war (Vermeidung von Erfolg-Flash-Folge)
        && ( !(PINB & (1<<PINB2) )) )
        {
            LED_state = LED_state_n;
            LED_state_zero = 0;
            //cli();                                          //disable ISR - shouldn't have affect in ISR!
        }
    if (LED_state_n == 0) LED_state_zero = 1;               //remember that there was a change to "LEDs==off" -> shows that there is not a "success"-flashing happening
    idle_cnt=0;                                             //reset idle counter
}

ISR(TIM1_COMPA_vect)
{
    //if (battime == 55)
    //{
        //battime = 0;
        //batt_meas();
    //}
    battime++;
}

void batt_meas()
{   
    uint16_t adcval = 0;
    
    adc_init();
    //#ifndef SIMULATING
    //_delay_ms(1);
    //#endif
        
    if (!(ADCSRA & (1<<ADSC) ))                             //is conversion running?
        {
            ADCSRA |= (1<<ADSC);                            //start conversion
            while (!(ADCSRA & (1<<ADIF)))
            {}
            adcval=ADC;
            ADCSRA |= (1<<ADIF);                        	//delete flag
                
            //battvolt=((adcval*4.48938)/1024);               // value based on simulation
            BatVal=((adcval*4.41)/1024);                    // 3*1.47 == Refvolt*R_divider
            if (BatVal<3.2 && BatVal>=3.1)
            {
                PORTA |= (1<<PINA5);
            }
            else
                PORTA &= ~(1<<PINA5);
        }
    #ifndef SIMULATING
    eeprom_busy_wait(); 
    //eeprom_write_byte(&eeBatVal,(BatVal-2)*100); // byte instead of float would reduce memsize
    eeprom_write_float(&eeBatVal,BatVal);
    #endif
    adc_disable();
}

void batt_state()
{
    //BatVal = (eeprom_read_byte(&eeBatVal)/100+2);
    #ifndef SIMULATING
    BatVal = eeprom_read_float(&eeBatVal);
    #else
    BatVal=3;
    #endif
    if ((BatVal < 3.2) && (BatVal >= 3.1))
    {
        PORTA |= (1<<PINA5);
    }
    else PORTA &= ~(1<<PINA5);
}

void adc_disable()
{
    ADCSRA &= ~(1<<ADEN); 
    power_adc_disable();
}

void adc_init()
{
    power_adc_enable();
    ADCSRA |= (1<<ADEN);                                        //enable ADC
    ADMUX &= ~((1<<REFS0) | (1<<REFS1) | (1<<MUX4) | (1<<MUX5));//high2: Vcc as Ref; lower6: ADC7 as in
    ADMUX |= (1<<MUX0) | (1<<MUX1) | (1<<MUX2);
    #ifndef SIMULATING
    ADCSRA |= (1<<ADPS0) | (1<<ADPS1) | (1<<ADPS2);             //adc clock prescale 1MHz/128=7.8kHz | 8MHz/128=62.5kHz
    //_delay_ms(1);
    #endif
    while (ADCSRA & (1<<ADSC) ) {                               // wait for completed conversion
    }
    (void) ADC;                                                 // have to read ADC once for valid results
    ADCSRA |= (1<<ADIF);
}

int main(void)
{   
    //DDRx - datadirection
    DDRA = 0b01100001;
    DDRB = 0b00000011;
    
    //PORTx - outputs / input pullups
    PORTA = 0b00000000;                                     //startconfig: all out=low
    PORTB = 0b00000101;                                     //startconfig: most out=low, but motor-man; mode_select pullup enable
    
    //ISR management
    GIMSK = (1<<PCIE0);                                     //enable PCINT Interrupt
    //PCMSK = 0b00000111;                                   //define LED-pins as interrupts
    PCMSK0 = 0b00001110;                                    //define LED-pins as interrupts
    
    #ifndef SIMULATING
    TCCR1B = 1<<CS12 | 0<<CS11 | 1<<CS10 | 1<<WGM12;        //1024 prescale; CTC mode
    #endif
    #ifdef SIMULATING
    TCCR1B = 0<<CS12 | 0<<CS11 | 1<<CS10 | 1<<WGM12;        //no prescale; CTC mode
    #endif
    OCR1A = 63920;                                          //counter compare value; compare*55 == 1h wait
    TIMSK1 |= (1<<OCIE1A);                                  //compare ISR

    #ifndef SIMULATING
    _delay_ms(1000);                                        //1s for full init
    #endif
    MotorFunc();
    GetSeed();                                              //set global variable g_nLastRandom
    TrackReset();
    batt_meas();
    SwitchFunc();
    
    sei();                                                  //enable interrupts
    
    //do your thing!
    while (1) {
        switch (LED_state) {
            case 0: WaitCount(); break;                     //handle waiting
            case 1: cli(); BlueHandle(); break;             //blue LED -> Poke-Stop
            case 2: cli(); GreenHandle(); break;            //green LED -> Mon-Catch
            case 4: cli(); RedHandle(); break;              //red LED -> Error
            case 6: cli(); YellowHandle(); break;           //yellow LED -> new mon
            case 7: cli(); WhiteHandle(); break;             //white LED -> catching or bag full
            //default: break;
        }
        #ifdef DEBUGING
            PORTA |= (1<<PINA6);                            //operation indication for debug
            #ifndef SIMULATING
            _delay_ms(8);
            #endif
            PORTA &= ~(1<<PINA6);
        #endif
        if (battime>=55)
        {
            batt_meas();
            battime=0;
        }        
    }
}

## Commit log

2019-03-10 Add files via upload
    initial versions
    [Button_plus.ipt, Case_bot_v5.stl, Case_top_v4.stl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]
2019-11-15 change to propper codebase
    correct pin assignment
    includes debugging mode & battery monitoring
    [PG+Ext_Attiny44A_Codebase.c]
2019-11-15 pdf of PCB layout
    v1.1 fixes a bug with diode pin assignment
2019-11-15 update to 1.1
    fixing diode pin assignment and routing
    [PGPExT_v1-1.kicad_pcb]
2020-05-01 Added Gerber-Files
    added Gerber-files for manufacturers that don't import KiCAD files
    removed old/faulty PCB version
    [PGPExT.kicad_pcb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]
